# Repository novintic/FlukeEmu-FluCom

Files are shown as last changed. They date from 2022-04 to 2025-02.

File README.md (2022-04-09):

# FlukeEmu-FluCom
A HW/SW solution for Fluke 9010 mainframe emulation

The Idea is to use a Raspberry Pi to run a Fluke 9010a emulator in software and interface with the hardware (pods) by means
of an add on board/hat (basically to shift the levels and provide power to the pod). So far we have progressed from a proof
of concept to a pretty solid and stable emulation.

The advantages of using an approach like this are many, amongst them:
* cheap Fluke 9010a mainframe replacement using modern technology and thereby adding stuff like network capability, wireless LAN, remote access/VNC, bluetooth etc ‚for free‘
* the interface board can supply all the power rails to the pod so only one 12V wall adapter is needed to power the RaspberryPi and the pods
* the whole setup is portable and compact, you could in theory put the whole thing inside your cabinet/UUT and comfortably use VNC to remote control the Fluke. You could also run the thing ‚headless‘ making it even smaller.

For further instruction on the fluCom board, please check: FlukeEmu-FluCom/fluCom/readme.md

For further instruction on the flukeEmuWx software, please check: FlukeEmu-FluCom/flukeEmuWx/readme.md

## Credits
We would like to credit Adam Courchesne (@onecircuit) for coming up with the idea of a Fluke emulator and hardware combination
and of course for being the first one to actually write one and make it available.

## See also
https://forums.arcade-museum.com/threads/flukeemu-flucom-fluke-9010a-microsystem-troubleshooter-emulator.503305/

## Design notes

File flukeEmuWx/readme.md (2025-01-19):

## Instructions for setting up FlukeEmuWx by Clemens (Novintic)

## Easy method:

1) Get a Raspberry PI 2, 3 or 4 with Raspi OS installed
2) Download the install script: https://raw.githubusercontent.com/novintic/FlukeEmu-FluCom/refs/heads/main/flukeEmuWx/build-flukeEmuWx.sh
3) make it executable: chmod u+x build-flukeEmuWx.sh
4) execute the script and wait.
5) Start flukeEmuWx from the menu/others folder

## Advanced method
You need:
* A Raspberry PI 2, 3 or 4 with Raspi OS installed
* Codeblocks IDE (if not installed, use add/remove software)
* Fluke 9010A ROMs 
* To connect a POD you need a FluCom HAT board. KiCad files are in folder: kicad

### Get FlukeEmuWx source files
* Download sources from: https://github.com/novintic/FlukeEmu-FluCom
* Create path: FlukeEmuWx
* Copy source files to path FlukeEmuWx

### Install wxWidgets (Grab a few beers, takes 1-2h!)
* Follow instructions: https://wiki.wxwidgets.org/Compiling_and_getting_started

### Install wiringPi (http://wiringpi.com/news/)
* wget https://unicorn.drogon.net/wiringpi-2.46-1.deb
* sudo dpkg -i wiringpi-2.46-1.deb

### Install pulseAudio
* sudo apt-get install -y libpulse-dev

### Install Fluke ROMs (we cannot supply these due to copyright)
* Copy the 3 ROM files to FlukeEmuWx/media
   * Files have to be named: 128C900.U9, 128C901.U19, 128C902.U21

### Start Codeblocks IDE
* Open project file: FlukeEmuWx/FlukeEmuWx.cbp
* Build the project

### Run flukeEmuWx
* Press the run button in codeblocks
* In order to run flukeEmuWx standalone, you need to place the 'media' folder in the same folder as the executable
   * The executable file 'FlukeEmuWx' is in the bin/Release or bin/Debug folder, depending on which target was built

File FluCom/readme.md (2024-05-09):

# FluCom
The FluCom Interface is a stack-on board (HAT) for a Raspberry Pi 3 or higher. It’s purpose is to interface with Pods for the Fluke 9000 series Microsystem Troubleshooter which is still used today to diagnose and repair vintage computer equipment such as arcade game pcbs.

It is designed to be used in conjunction with the FlukeEmu software.

The idea behind the project is to use readily available parts to provide an as-simple-as-possible (cheap) way to replace a Fluke 9010a Mainframe.

The board and its design files are made available under the CERN Open Hardware License: https://ohwr.org/project/cernohl/wikis/Documents/CERN-OHL-version-2

Novitntic 03/2022

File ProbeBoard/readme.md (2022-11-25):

# Probe add-on- board for FluCom Raspberry Pi HAT

This add-on board for the FluCom Raspberry Pi HAT provides full probe functionality for the FlukeEmu/FluCom hardware/software Emulation of the Fluke 9010A Micro-System Troubleshooter.

Basically this makes the Fluke 9010A emulation feature- complete.

As much of the original circuitry as possible was implemented using a Raspberry PICO microcontroller. 

However, due to the original design of the probe, a significant amount of analog circuitry had to be reproduced in order to keep the system working with legacy probes.

The board and its design files are made available under the CERN Open Hardware License: https://ohwr.org/project/cernohl/wikis/Documents/CERN-OHL-version-2

Novitntic 11/2022

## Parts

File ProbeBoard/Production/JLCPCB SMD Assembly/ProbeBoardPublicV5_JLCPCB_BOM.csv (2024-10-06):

Comment | Designator | Footprint | LCSC
6.8uF 35V | C1,C2 | Capacitor_SMD:C_0805_2012Metric_Pad1.18x1.45mm_HandSolder | C5139488
100uF | C3 | Capacitor_THT:CP_Radial_D5.0mm_P2.50mm
0.1uF | C4,C5 | Capacitor_SMD:C_0805_2012Metric_Pad1.18x1.45mm_HandSolder | C126469
2-10pF | C51 | Capacitor_SMD:C_1210_3225Metric
5-50pF | C52 | Capacitor_SMD:C_1210_3225Metric
0.22uF | C53,C58,C59,C60,C61,C62,C71 | Capacitor_SMD:C_0805_2012Metric_Pad1.18x1.45mm_HandSolder | C152875
.001uF | C54,C55 | Capacitor_SMD:C_0805_2012Metric_Pad1.18x1.45mm_HandSolder | C46553
22uF 15V Tant | C56 | Capacitor_SMD:C_0805_2012Metric_Pad1.18x1.45mm_HandSolder | C77071
10nF | C7 | Capacitor_SMD:C_0805_2012Metric_Pad1.18x1.45mm_HandSolder | C303893
1N4448 | CR3,CR4,CR5,CR6,CR7,CR13 | Diode_SMD:D_SOD-123 | C8601
MBR120(520?) | D1 | Diode_SMD:Nexperia_CFP3_SOD-123W | C130880
LED RED | D2 | LED_SMD:LED_0805_2012Metric_Pad1.15x1.40mm_HandSolder | C94741
LED GREEN | D3 | LED_SMD:LED_0805_2012Metric_Pad1.15x1.40mm_HandSolder | C2297
BSS138 | Q1,Q2,Q4,Q5 | Package_TO_SOT_SMD:SOT-23 | C5190146
10K | R13,R14,R15,R16 | Resistor_SMD:R_0805_2012Metric_Pad1.20x1.40mm_HandSolder | C510098
200R | R22,R23,R41 | Resistor_SMD:R_0805_2012Metric_Pad1.20x1.40mm_HandSolder | C328389
330R | R24 | Resistor_SMD:R_0805_2012Metric_Pad1.20x1.40mm_HandSolder | C328393
150R | R25 | Resistor_SMD:R_0805_2012Metric_Pad1.20x1.40mm_HandSolder | C328383
15K(1%) | R26 | Resistor_SMD:R_0805_2012Metric_Pad1.20x1.40mm_HandSolder | C706307
4420R(1%) | R27 | Resistor_SMD:R_0805_2012Metric_Pad1.20x1.40mm_HandSolder | C185701
200R(1%) | R28 | Resistor_SMD:R_0805_2012Metric_Pad1.20x1.40mm_HandSolder | C328389
100R(1%) | R29 | Resistor_SMD:R_0805_2012Metric_Pad1.20x1.40mm_HandSolder | C706199
300R | R3,R4 | Resistor_SMD:R_0805_2012Metric_Pad1.20x1.40mm_HandSolder | C114529
2.2K | R30,R31 | Resistor_SMD:R_0805_2012Metric_Pad1.20x1.40mm_HandSolder | C163972
22K | R32 | Resistor_SMD:R_0805_2012Metric_Pad1.20x1.40mm_HandSolder
10K? 5K? | R33 | Resistor_SMD:R_0805_2012Metric_Pad1.20x1.40mm_HandSolder
750R | R38 | Resistor_SMD:R_0805_2012Metric_Pad1.20x1.40mm_HandSolder | C416169
1K | R5,R6,R10,R11,R39 | Resistor_SMD:R_0805_2012Metric_Pad1.20x1.40mm_HandSolder | C115316
100R | R52 | Resistor_SMD:R_0805_2012Metric_Pad1.20x1.40mm_HandSolder | C706199
510R | R56 | Resistor_SMD:R_0805_2012Metric_Pad1.20x1.40mm_HandSolder | C228886
JFE2140 | U1 | Package_SO:SOIC-8_3.9x4.9mm_P1.27mm | C2915160
LM361 | U2,U3 | Package_SO:SOIC-14_3.9x8.7mm_P1.27mm | C2868536
SN74LV1T34DBV | U4,U6 | Package_TO_SOT_SMD:SOT-23-5 | C100024

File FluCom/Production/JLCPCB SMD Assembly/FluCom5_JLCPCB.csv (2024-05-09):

Comment | Designator | Footprint | LCSC
0.1uF | C1,C2,C3,C4,C5,C6,C9,C10 | Capacitor_SMD:C_0805_2012Metric_Pad1.18x1.45mm_HandSolder | C138340
4.7uF | C7 | Capacitor_SMD:C_0805_2012Metric_Pad1.18x1.45mm_HandSolder | C77077
10uF | C8 | Capacitor_SMD:C_0805_2012Metric_Pad1.18x1.45mm_HandSolder | C83061
B320 | D1 | Diode_SMD:D_SMC | C134448
LED_Small | D2,D3,D4,D5 | LED_SMD:LED_0805_2012Metric_Pad1.15x1.40mm_HandSolder | C189307
BSS138 | Q1,Q2 | Package_TO_SOT_SMD:SOT-23 | C5190146
R_Small | R1 | Resistor_SMD:R_0805_2012Metric_Pad1.20x1.40mm_HandSolder | C510098
300R | R10,R11,R13 | Resistor_SMD:R_0805_2012Metric_Pad1.20x1.40mm_HandSolder | C365284
700R | R12 | Resistor_SMD:R_0805_2012Metric_Pad1.20x1.40mm_HandSolder | C229239
10K | R2,R3,R4,R5,R14 | Resistor_SMD:R_0805_2012Metric_Pad1.20x1.40mm_HandSolder | C510098
TXS0104EPW | U1,U2,U3 | Package_SO:SOIC-14_3.9x8.7mm_P1.27mm | C79342
SN74LV1T34DBV | U6,U7 | Package_TO_SOT_SMD:SOT-23-5 | C100024

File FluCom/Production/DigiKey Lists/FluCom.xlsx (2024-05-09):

Das Herkunftsland kann sich zum Zeitpunkt des Versands geändert haben.
Die angezeigten HTSUS- und ECCN-Informationen dienen nur zu Informationszwecken und stellen keine Zusicherung oder Garantie für die Richtigkeit oder Zuverlässigkeit dieser Klassifizierungen dar. Alle Informationen werden ohne Gewähr zur Verfügung gestellt und können ohne vorherige Ankündigung geändert werden. Jede Verwendung der bereitgestellten Informationen erfolgt ohne Rechtsansprüche an Digi-Key und auf Risiko des Benutzers.
Index | Hersteller-Teilenummer | Herstellername | Beschreibung | Verfügbarkeit | Lagerstatus | Verlust % | Gewünschte Menge 1 | Packungsmenge 1 | Packungstyp 1 | Digi-Key-Teilenr. 1 | Stückpreis 1 | Gesamtpreis 1 | Mindestbestellmenge 1 | Kundenreferenz | Gewünschte Teilenummer | Lieferzeit in Wochen | Datenblatt | Referenzbezeichner | US-Einfuhrzoll | Hinweis | Status der Komponente | RoHS-Status | Feuchteempfindlichkeit (MSL) | ECCN | HTSUS | Herkunftsland | Informationen zur Umweltverträglichkeit | Original-Teilenummern | Bild | Product Notes
1 | 5747842-3 | TE Connectivity AMP Connectors | CONN D-SUB PLUG 25POS R/A SLDR | 513 | Artikel auf Lager |  | 1 | 1 | Tray | A32099-ND | 4.91000 | Fr. 4.91 | 1 |  | A32099-ND | 11 | https://www.te.com/commerce/DocumentDelivery/DDEController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 |  | N/A |  | Aktiv | RoHS-konform | 1 (Unbegrenzt) | EAR99 | 8536.69.4040 | Mexico | http://www.te.com/commerce/alt/SinglePartSearch.do?PN=5747842-3&dest=stmt | A32099-ND | https://mm.digikey.com/Volume0/opasdata/d220001/medias/images/922/5747842-3.jpg
2 | TB004-508-02BE | CUI Devices | TERMINAL BLOCK, SCREW TYPE, 5.08 | 425 | Artikel auf Lager |  | 2 | 2 | Bag | 102-6179-ND | 0.53000 | Fr. 1.06 | 1 |  | 102-6179-ND | 18 | https://www.cuidevices.com/product/resource/tb004-508.pdf |  | Gilt unter Umständen für Lieferungen in die USA. |  | Aktiv | RoHS3-konform | Nicht anwendbar | EAR99 | 8536.90.4000 | China | https://www.cuidevices.com/product/resource/ce-declaration/tb004-508-series|https://www.cuidevices.com/product/resource/material-compliance/tb004-508-series | 102-6179-ND | https://mm.digikey.com/Volume0/opasdata/d220001/medias/images/568/MFG_TB004-508-02BE.jpg
3 | TB004-508-03BE | CUI Devices | TERMINAL BLOCK, SCREW TYPE, 5.08 | 994 | Artikel auf Lager |  | 1 | 1 | Bag | 102-6180-ND | 0.79000 | Fr. 0.79 | 1 |  | 102-6180-ND | 18 | https://www.cuidevices.com/product/resource/tb004-508.pdf |  | Gilt unter Umständen für Lieferungen in die USA. |  | Aktiv | RoHS3-konform | Nicht anwendbar | EAR99 | 8536.90.4000 | China | https://www.cuidevices.com/product/resource/ce-declaration/tb004-508-series|https://www.cuidevices.com/product/resource/material-compliance/tb004-508-series | 102-6180-ND | https://mm.digikey.com/Volume0/opasdata/d220001/medias/images/568/MFG_TB004-508-03BE.jpg
4 | B0505S-1WR3 | Mornsun America, LLC | DC DC CONVERTER 5V 1W | 26’061 | Artikel auf Lager |  | 1 | 1 | Tube | 2725-B0505S-1WR3-ND | 4.55000 | Fr. 4.55 | 1 |  | 2725-B0505S-1WR3-ND | 15 | https://www.mornsun-power.com/html/pdf/B0505S-1WR3.html |  | Gilt unter Umständen für Lieferungen in die USA. |  | Aktiv | RoHS-konform | 1 (Unbegrenzt) | EAR99 | 8504.40.9580 | China |  | 2725-B0505S-1WR3-ND | https://mm.digikey.com/Volume0/opasdata/d220001/medias/images/4414/MFG_B0505S-1WR3.JPG
5 | PJ-059AH | CUI Devices | CONN PWR JACK 2X5.5MM SOLDER | 1’160 | Artikel auf Lager |  | 1 | 1 | Tray | CP-059AH-ND | 0.84000 | Fr. 0.84 | 1 |  | CP-059AH-ND | 7 | https://www.cuidevices.com/product/resource/pj-059ah.pdf |  | N/A |  | Aktiv | RoHS3-konform | 1 (Unbegrenzt) | EAR99 | 8536.69.4040 | China | https://www.cuidevices.com/product/resource/material-compliance/pj-059ah | CP-059AH-ND | https://mm.digikey.com/Volume0/opasdata/d220001/medias/images/923/PJ-059AH.JPG
6 | PPPC202LFBN-RC | Sullins Connector Solutions | CONN HDR 40POS 0.1 GOLD PCB | 93’538 | Artikel auf Lager |  | 1 | 1 | Tray | S7123-ND | 2.09000 | Fr. 2.09 | 1 |  | S7123-ND | 11 | https://mm.digikey.com/Volume0/opasdata/d220001/medias/docus/937/Female_Headers.100_DS.pdf |  | N/A |  | Aktiv | RoHS3-konform | 1 (Unbegrenzt) | EAR99 | 8536.69.4040 | Taiwan | https://www.sullinscorp.com/wp-content/uploads/2021/08/Sullins-REACH-219-SVHC-Compliant-Statement.pdf|https://www.sullinscorp.com/wp-content/uploads/2019/03/Sullins-RoHS-Compliant-Statement.pdf | S7123-ND | https://mm.digikey.com/Volume0/opasdata/d220001/medias/images/1144/PPPC202LFBN-RC.jpg
7 | 67997-226HLF | Amphenol ICC (FCI) | CONN HEADER VERT 26POS 2.54MM | 3’237 | Artikel auf Lager |  | 1 | 1 | Bag | 609-3240-ND | 1.30000 | Fr. 1.30 | 1 |  | 609-3240-ND | 22 | https://cdn.amphenol-cs.com/media/wysiwyg/files/drawing/67996.pdf |  | N/A |  | Aktiv | RoHS-konform | 1 (Unbegrenzt) | EAR99 | 8536.69.4040 | France |  | 609-3240-ND | https://mm.digikey.com/Volume0/opasdata/d220001/medias/images/2511/67997-xxx.jpg
8 | SSW-120-02-G-D-LL | Samtec Inc. | CONN RCPT 40POS 0.1 GOLD PCB | 333 | Artikel auf Lager |  | 1 | 1 | Bulk | SSW-120-02-G-D-LL-ND | 7.92000 | Fr. 7.92 | 1 |  | SSW-120-02-G-D-LL-ND | 5 | https://suddendocs.samtec.com/productspecs/tsw-sxx.pdf |  | N/A |  | Aktiv | RoHS3-konform | Nicht anwendbar | EAR99 | 8536.69.4040 | Malaysia |  | SSW-120-02-G-D-LL-ND | https://mm.digikey.com/Volume0/opasdata/d220001/medias/images/4842/SSW-120-02-G-D-LL.jpg
9 | SSW-120-01-G-D-LL | Samtec Inc. | CONN RCPT 40POS 0.1 GOLD PCB | 22 | Artikel auf Lager |  | 1 | 1 | Bulk | SSW-120-01-G-D-LL-ND | 7.68000 | Fr. 7.68 | 1 |  | SSW-120-01-G-D-LL-ND | 5 | https://suddendocs.samtec.com/productspecs/tsw-sxx.pdf |  | N/A |  | Aktiv | RoHS3-konform | Nicht anwendbar | EAR99 | 8536.69.4040 | Vietnam |  | SSW-120-01-G-D-LL-ND | https://mm.digikey.com/Volume0/opasdata/d220001/medias/images/4840/SSW-120-01-G-D-LL.jpg
10 | SMH150-LPSE-D25-ST-BK | Sullins Connector Solutions | CONN HEADER VERT 50POS 1MM | 1’234 | Artikel auf Lager |  | 1 | 1 | Bag | S9258-ND | 8.11000 | Fr. 8.11 | 1 |  | S9258-ND | 11 | https://s3.amazonaws.com/catalogspreads-pdf/PAGE88-89%201mm%20SMH%20SERIES%20MALE%20HDR%20ST%20RA%20SMT.pdf |  | N/A |  | Aktiv | RoHS3-konform | 1 (Unbegrenzt) | EAR99 | 8536.69.4040 | Taiwan | https://www.sullinscorp.com/wp-content/uploads/2021/08/Sullins-REACH-219-SVHC-Compliant-Statement.pdf|https://www.sullinscorp.com/wp-content/uploads/2019/03/Sullins-RoHS-Compliant-Statement.pdf | S9258-ND | https://mm.digikey.com/Volume0/opasdata/d220001/medias/images/606/SMH150-LPSE-D25-ST-BK.JPG
11 | QPC02SXGN-RC | Sullins Connector Solutions | CONN JUMPER SHORTING .100" GOLD | 60’764 | Artikel auf Lager |  | 8 | 8 | Bag | S9337-ND | 0.09000 | Fr. 0.72 | 1 |  | S9337-ND | 11 | https://s3.amazonaws.com/catalogspreads-pdf/PAGE128-129%20.100%20JUMPER.pdf |  | N/A |  | Aktiv | RoHS3-konform | 1 (Unbegrenzt) | EAR99 | 8536.90.4000 | Taiwan | https://www.sullinscorp.com/wp-content/uploads/2021/08/Sullins-REACH-219-SVHC-Compliant-Statement.pdf|https://www.sullinscorp.com/wp-content/uploads/2019/03/Sullins-RoHS-Compliant-Statement.pdf | S9337-ND | https://mm.digikey.com/Volume0/opasdata/d220001/medias/images/386/QPC02SXGN-RC.JPG

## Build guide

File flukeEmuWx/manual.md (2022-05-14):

# FlukeEmuWx User Manual

## 1 Introduction
FlukeEmuWx is a software which emulates a Fluke 9010A mainframe on a Raspberry Pie (RPI) computer. FlukeEmuWx use the GPIOs on the RPI to communicate with the pods. Since the RPI outputs are 3.3V and the pod are running on 5V, a level converter board is required (the FluCom2).
FlukeEmuWx works by running a Z80 emulator that executes the original ROM code. The user interface elements like display and keyboard are emulated on the RPI.

## 2 Installation
See readme.txt for how to build FlukeEmuWx or check out the nice manuals on [1] by cyberbarter.

The media folder either needs to be in the same folder as the executable or you have to add the path of the media folder the environment variable PATH.

[1] https://forums.arcade-museum.com/threads/flukeemu-flucom-fluke-9010a-microsystem-troubleshooter-emulator.503305/page-5 

## 3 Features
### 3.1 Tape drive emulation
Clicking the tape icon in the top right corner opens a file dialog where you can select a tape file. Alternatively you can use the settings menu entry 'Tape file'. The tape file must exist already  (use touch yourfile.txt on the command line to create an empty file for writing).

### 3.2 Serial port emulation
#### 3.2.1 Host serial port
Setting the serial port flukeEmuWx will route the Fluke 9010B serial port to a real serial port on your RPI. 
The serial port on the RPI GPIOs is named /dev/serial0. You will need a converter board (like FTDI TTL232R, 3.3v levels) to connect the RPI UART to a USB port on a PC. The permissions for the current user to access the serial port file must be set correctly. This is done by adding the current user to the group 'tty'. The port might be already in use by a serial console. In this case you need to disable the console using "sudo raspi-config" (interface options, disable console, enable serial port hardware).

#### 3.2.1 Serial port to/from file
In order to send a file to the serial port of the Fluke 9010 emulation, select 'send file' in the settings/serial port menu. This will
open a file dialog, where you can choose the file. Once done, the file content will be fed to the Fluke 9010 serial port as soon as
you read from the port. If the file has been fully read, it will be automatically closed.

In order to receive a file from the emulation, select 'receive file' in the settings/serial port menu. This will
open a file dialog, where you can choose the file. Once done, any data sent through the serial port of the Fluke 9010 emulation 
will be written to this file. To detach the file from the serial port, select 'receive file' in the menu and press cancel in the file dialog.

### 3.3 Full screen mode
Enter fullscreen by 
* using the menu "settings/fullscreen"
* Pressing F5
* Left click in the (Fluke emulation) display area and use the pop-up menu
Exit fullscreen by 
* Pressing F5
* Left click in the (Fluke emulation) display area and use the pop-up menu

## Appendix
### A.1 Using FlukeEmuWx over VNC
A convienent way of using FlukeEmuWx on the RPI is to use VNC. This allows you to use the screen, keyboard and mouse
of the computer running the VNC client. You do not need a screen or keyobard connected to the RPI, but the RPI needs
a network connection, either by Ethernet or WLAN. Realvnc is a good choice for a VNC client for For windows.

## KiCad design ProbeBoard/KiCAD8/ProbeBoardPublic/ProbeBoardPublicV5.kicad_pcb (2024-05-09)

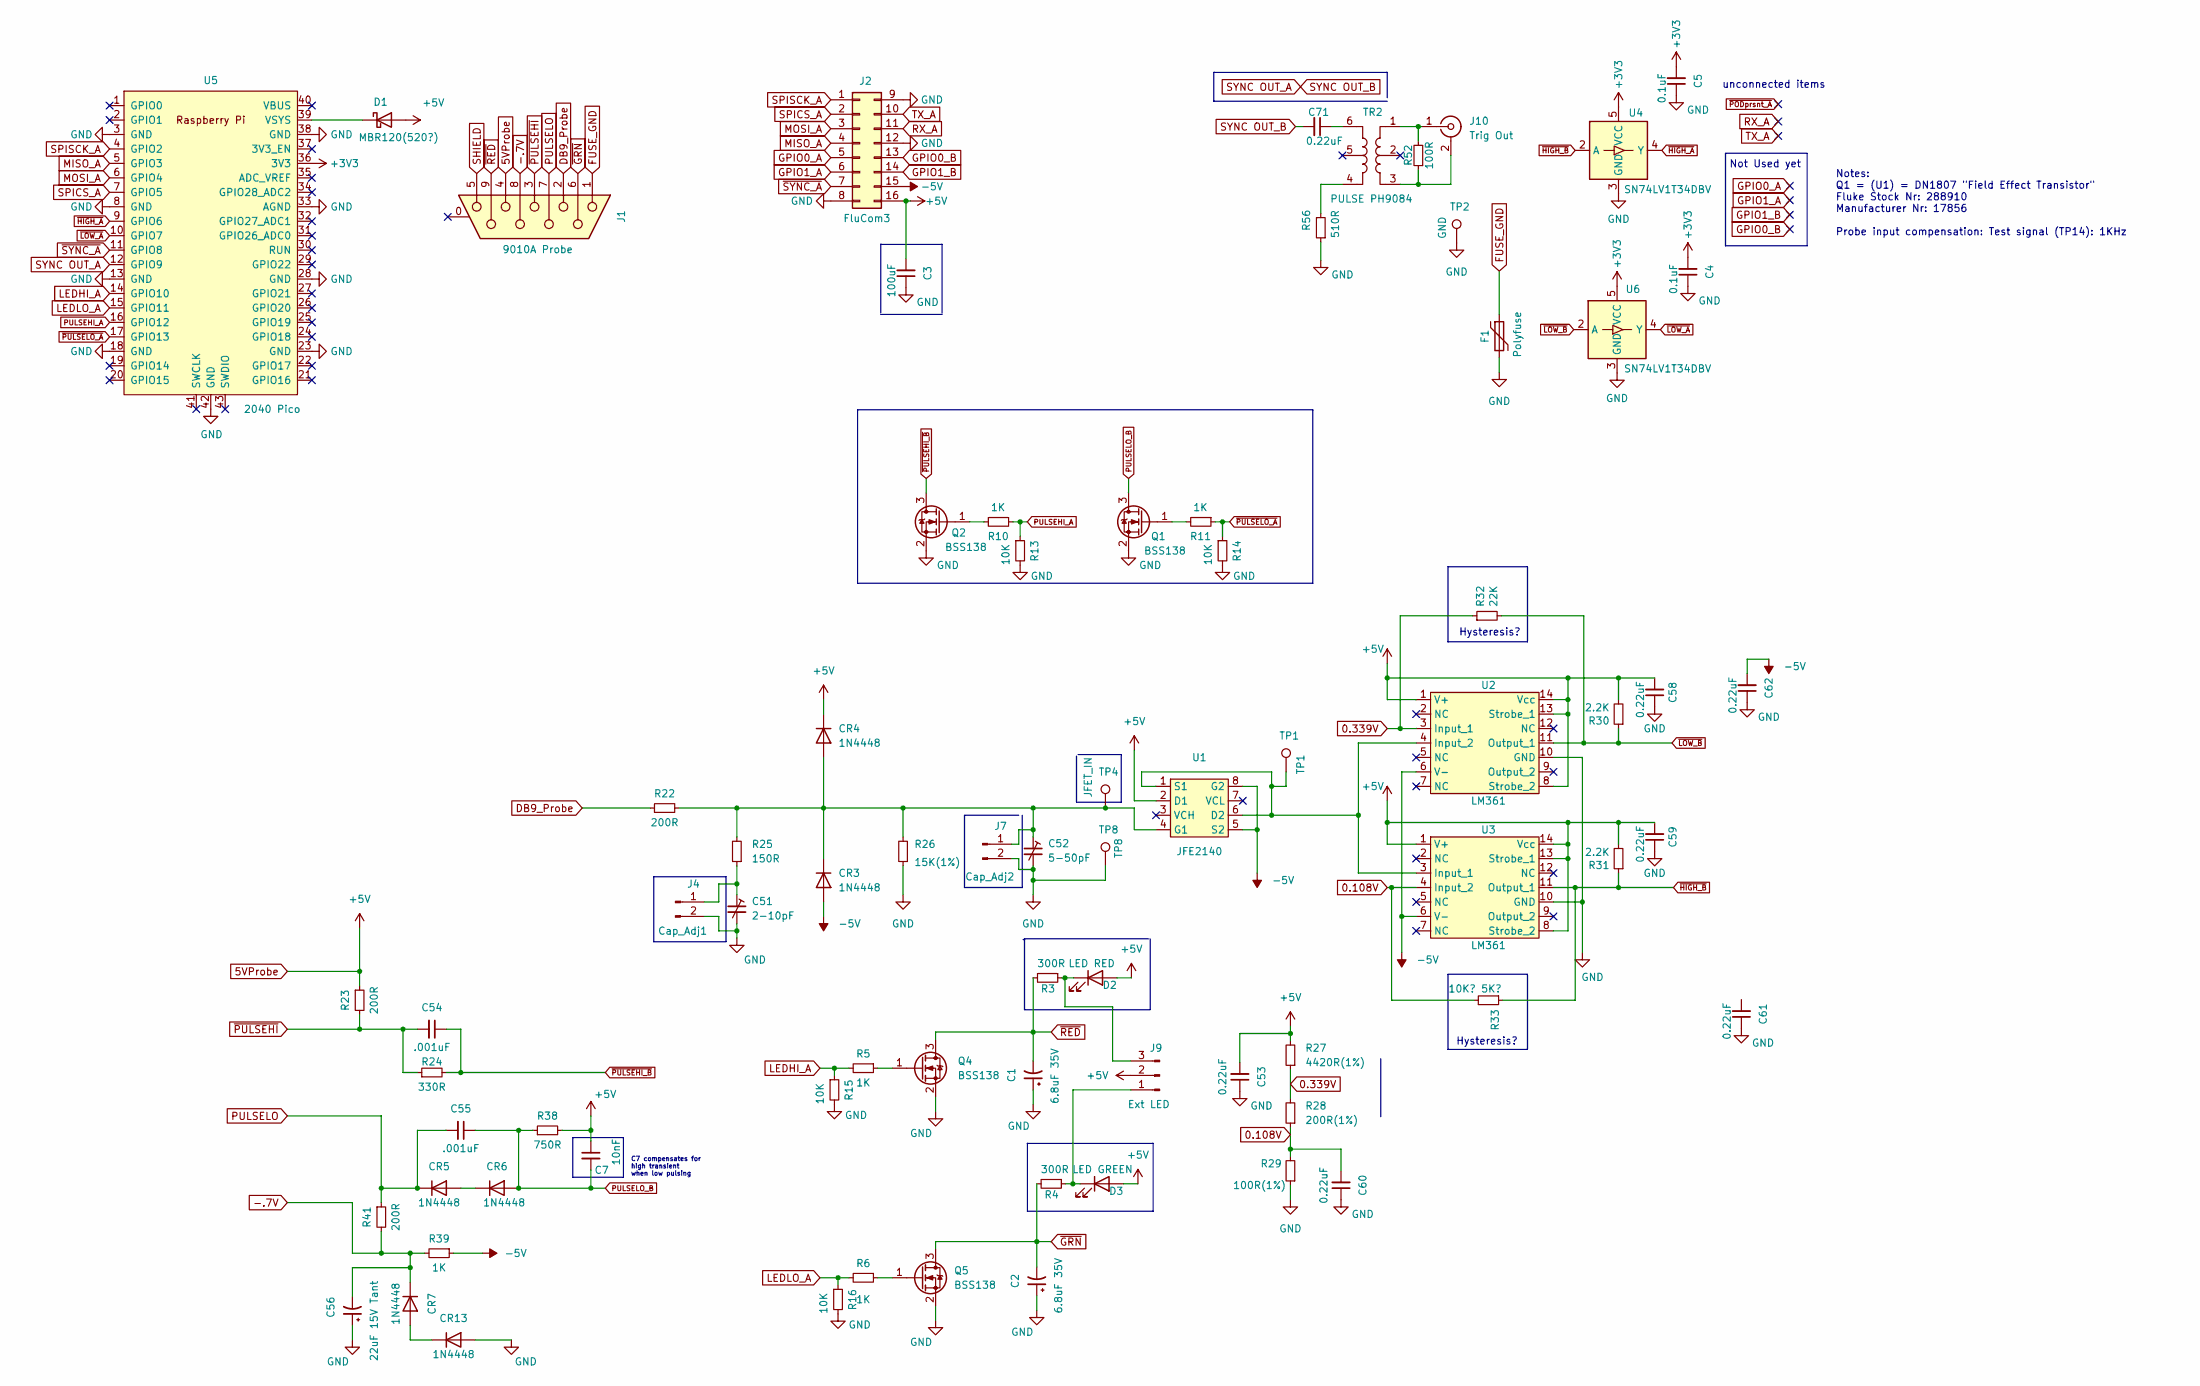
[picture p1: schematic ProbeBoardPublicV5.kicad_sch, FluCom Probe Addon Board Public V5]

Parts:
C1, C2: 6.8uF 35V; C_0805_2012Metric_Pad1.18x1.45mm_HandSolder; LCSC C5139488
C3: 100uF; CP_Radial_D5.0mm_P2.50mm
C4, C5: 0.1uF; C_0805_2012Metric_Pad1.18x1.45mm_HandSolder; LCSC C126469
C7: 10nF; C_0805_2012Metric_Pad1.18x1.45mm_HandSolder; LCSC C303893
C51: 2-10pF; C_1210_3225Metric
C52: 5-50pF; C_1210_3225Metric
C53, C58, C59, C60, C61, C62, C71: 0.22uF; C_0805_2012Metric_Pad1.18x1.45mm_HandSolder; LCSC C152875
C54, C55: .001uF; C_0805_2012Metric_Pad1.18x1.45mm_HandSolder; LCSC C46553
C56: 22uF 15V Tant; C_0805_2012Metric_Pad1.18x1.45mm_HandSolder; LCSC C77071
CR3, CR4, CR5, CR6, CR7, CR13: 1N4448; D_SOD-123; LCSC C8601
D1: MBR120(520?); Nexperia_CFP3_SOD-123W; LCSC C130880
D2: LED RED; LED_0805_2012Metric_Pad1.15x1.40mm_HandSolder; LCSC C94741
D3: LED GREEN; LED_0805_2012Metric_Pad1.15x1.40mm_HandSolder; LCSC C2297
F1: Polyfuse; C_1206_3216Metric_Pad1.33x1.80mm_HandSolder
J1: 9010A Probe; DSUB-9_Female_Horizontal_P2.77x2.84mm_EdgePinOffset4.94mm_H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
J2: FluCom3; PinHeader_2x08_P2.54mm_Vertical
J4: Cap_Adj1; PinHeader_1x02_P2.54mm_Vertical
J7: Cap_Adj2; PinHeader_1x02_P2.54mm_Vertical
J9: Ext LED; PinHeader_1x03_P2.54mm_Vertical
J10: Trig Out; BNC_Amphenol_B6252HB-NPP3G-50_Horizontal
Q1, Q2, Q4, Q5: BSS138; SOT-23; LCSC C5190146
R3, R4: 300R; R_0805_2012Metric_Pad1.20x1.40mm_HandSolder; LCSC C114529
R5, R6, R10, R11, R39: 1K; R_0805_2012Metric_Pad1.20x1.40mm_HandSolder; LCSC C115316
R13, R14, R15, R16: 10K; R_0805_2012Metric_Pad1.20x1.40mm_HandSolder; LCSC C510098
R22, R23, R41: 200R; R_0805_2012Metric_Pad1.20x1.40mm_HandSolder; LCSC C328389
R24: 330R; R_0805_2012Metric_Pad1.20x1.40mm_HandSolder; LCSC C328393
R25: 150R; R_0805_2012Metric_Pad1.20x1.40mm_HandSolder; LCSC C328383
R26: 15K(1%); R_0805_2012Metric_Pad1.20x1.40mm_HandSolder; LCSC C706307
R27: 4420R(1%); R_0805_2012Metric_Pad1.20x1.40mm_HandSolder; LCSC C185701
R28: 200R(1%); R_0805_2012Metric_Pad1.20x1.40mm_HandSolder; LCSC C328389
R29: 100R(1%); R_0805_2012Metric_Pad1.20x1.40mm_HandSolder; LCSC C706199
R30, R31: 2.2K; R_0805_2012Metric_Pad1.20x1.40mm_HandSolder; LCSC C163972
R32: 22K; R_0805_2012Metric_Pad1.20x1.40mm_HandSolder
R33: 10K? 5K?; R_0805_2012Metric_Pad1.20x1.40mm_HandSolder
R38: 750R; R_0805_2012Metric_Pad1.20x1.40mm_HandSolder; LCSC C416169
R52: 100R; R_0805_2012Metric_Pad1.20x1.40mm_HandSolder; LCSC C706199
R56: 510R; R_0805_2012Metric_Pad1.20x1.40mm_HandSolder; LCSC C228886
TP1: TP1; PinHeader_1x01_P2.54mm_Vertical
TP2: GND; PinHeader_1x01_P2.54mm_Vertical
TP4: JFET_IN; PinHeader_1x01_P2.54mm_Vertical
TP8: TP8; PinHeader_1x01_P2.54mm_Vertical
TR2: PULSE PH9084; Pulse_P0926NL
U1: JFE2140; SOIC-8_3.9x4.9mm_P1.27mm; LCSC C2915160
U2, U3: LM361; SOIC-14_3.9x8.7mm_P1.27mm; LCSC C2868536
U4, U6: SN74LV1T34DBV; SOT-23-5; LCSC C100024
U5: 2040 Pico; RPi_Pico_SMD_TH

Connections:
0.108V: C60.2, R28.1, R29.2, R33.2, U3.4 (Input_2)
0.339V: R27.1, R28.2, R32.1, U2.3 (Input_1)
5VProbe: C3.2, C7.1, C53.2, C58.2, C59.2, CR4.1 (K), D1.2 (A), D2.2 (A), D3.2 (A), J1.4, J2.16, J9.2, R23.1, R27.2, R30.2, R31.2, R38.2, U1.2 (D1), U2.1 (V+), U2.8 (Strobe_2), U2.13 (Strobe_1), U2.14 (Vcc), U3.1 (V+), U3.8 (Strobe_2), U3.13 (Strobe_1), U3.14 (Vcc)
+3V3: C4.2, C5.2, U4.5 (VCC), U5.36 (3V3), U6.5 (VCC)
-5V: C62.2, CR3.2 (A), J2.15, R39.1, U1.5 (S2), U1.8 (G2), U2.6 (V-), U3.6 (V-)
-.7V: C56.2, CR7.1 (K), J1.8, R39.2, R41.2
DB9_Probe: J1.2, R22.1
FUSE_GND: F1.1, J1.1
GND: C1.1, C2.1, C3.1, C4.1, C5.1, C51.2, C52.2, C53.1, C56.1, C58.1, C59.1, C60.1, C61.1, C62.1, CR13.2 (A), F1.2, J2.8, J2.9, J2.12, J4.2, J7.2, Q1.2 (S), Q2.2 (S), Q4.2 (S), Q5.2 (S), R13.2, R14.2, R15.2, R16.2, R26.1, R29.1, R56.1, TP2.1, TP8.1, U2.10 (GND), U3.10 (GND), U4.3 (GND), U5.3 (GND), U5.8 (GND), U5.13 (GND), U5.18 (GND), U5.23 (GND), U5.28 (GND), U5.33 (AGND), U5.38 (GND), U5.42 (GND), U6.3 (GND)
GPIO0_A: J2.5
GPIO0_B: J2.13
GPIO1_A: J2.6
GPIO1_B: J2.14
LEDHI_A: R5.2, R15.1, U5.14 (GPIO10)
LEDLO_A: R6.2, R16.1, U5.15 (GPIO11)
MISO_A: J2.4, U5.5 (GPIO3)
MOSI_A: J2.3, U5.6 (GPIO4)
unnamed: C71.1, TR2.6
unnamed: C52.1, CR3.1 (K), CR4.2 (A), J7.1, R22.2, R25.2, R26.2, TP4.1, U1.4 (G1)
unnamed: CR5.2 (A), CR6.1 (K)
unnamed: CR7.2 (A), CR13.1 (K)
unnamed: D1.1 (K), U5.39 (VSYS)
unnamed: D2.1 (K), J9.3, R3.1
unnamed: D3.1 (K), J9.1, R4.1
unnamed: C51.1, J4.1, R25.1
unnamed: J10.2 (Ext), R52.1, TR2.3
unnamed: J10.1 (In), R52.2, TR2.1
unnamed: Q1.1 (G), R11.2
unnamed: Q2.1 (G), R10.2
unnamed: Q4.1 (G), R5.1
unnamed: Q5.1 (G), R6.1
unnamed: R56.2, TR2.4
unnamed: TP1.1, U1.1 (S1), U1.6 (D2), U2.4 (Input_2), U3.3 (Input_1)
PULSEHI_A: R10.1, R13.1, U5.16 (GPIO12)
PULSELO: C55.2, CR5.1 (K), J1.7, R41.1
PULSELO_B: C7.2, C55.1, CR6.2 (A), Q1.3 (D), R38.1
RX_A: J2.11
SHIELD: J1.5
SPICS_A: J2.2, U5.7 (GPIO5)
SPISCK_A: J2.1, U5.4 (GPIO2)
SYNC OUT_A: C71.2, U5.12 (GPIO9)
TX_A: J2.10
~GRN: C2.2, J1.6, Q5.3 (D), R4.2
~HIGH_A: U4.4 (Y), U5.9 (GPIO6)
~HIGH_B: R31.1, R33.1, U3.11 (Output_1), U4.2 (A)
~LOW_A: U5.10 (GPIO7), U6.4 (Y)
~LOW_B: R30.1, R32.2, U2.11 (Output_1), U6.2 (A)
~PULSEHI_B: C54.1, Q2.3 (D), R24.2
~PULSEHI: C54.2, J1.3, R23.2, R24.1
~PULSELO_A: R11.1, R14.1, U5.17 (GPIO13)
~RED: C1.2, J1.9, Q4.3 (D), R3.2
~SYNC_A: J2.7, U5.11 (GPIO8)

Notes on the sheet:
Hysteresis?
C7 compensates for high transient when low pulsing
unconnected items
Notes: Q1 = (U1) = DN1807 "Field Effect Transistor" Fluke Stock Nr: 288910 Manufacturer Nr: 17856 Probe input compensation: Test signal (TP14): 1KHz
Not Used yet

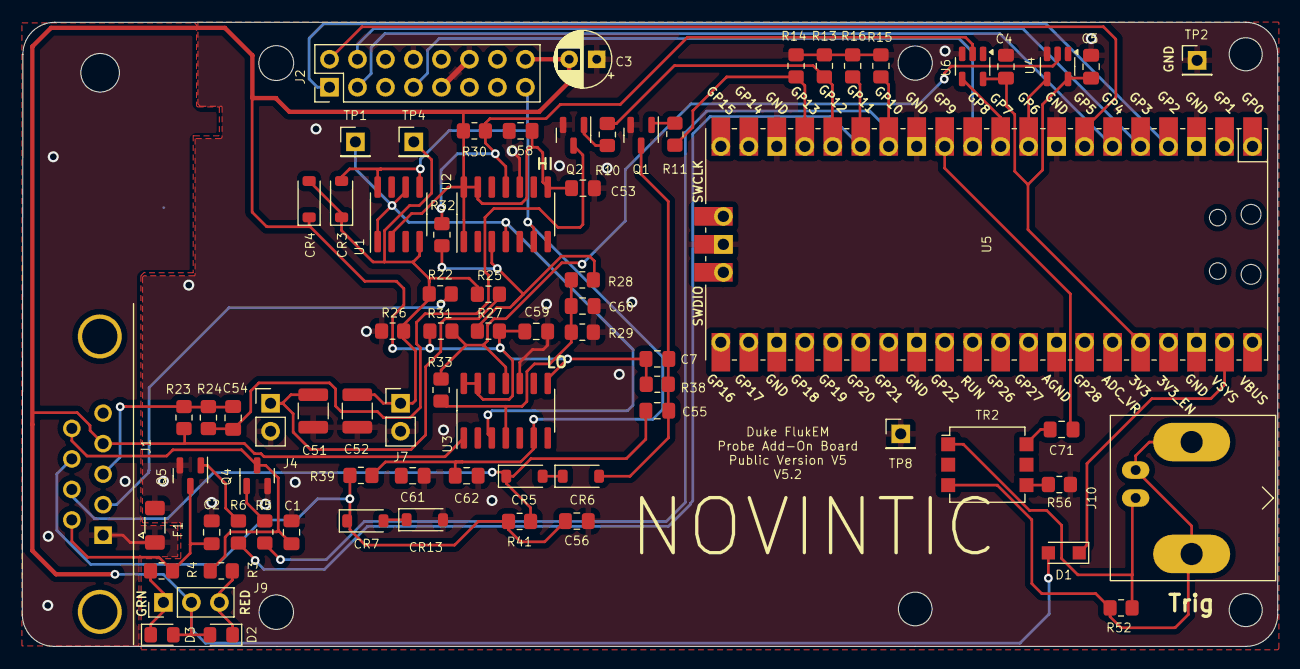
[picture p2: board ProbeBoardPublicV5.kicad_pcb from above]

Board: 2 copper layers, 114.0 x 56.6 mm, 76 parts (0 on the bottom side), 45 nets.

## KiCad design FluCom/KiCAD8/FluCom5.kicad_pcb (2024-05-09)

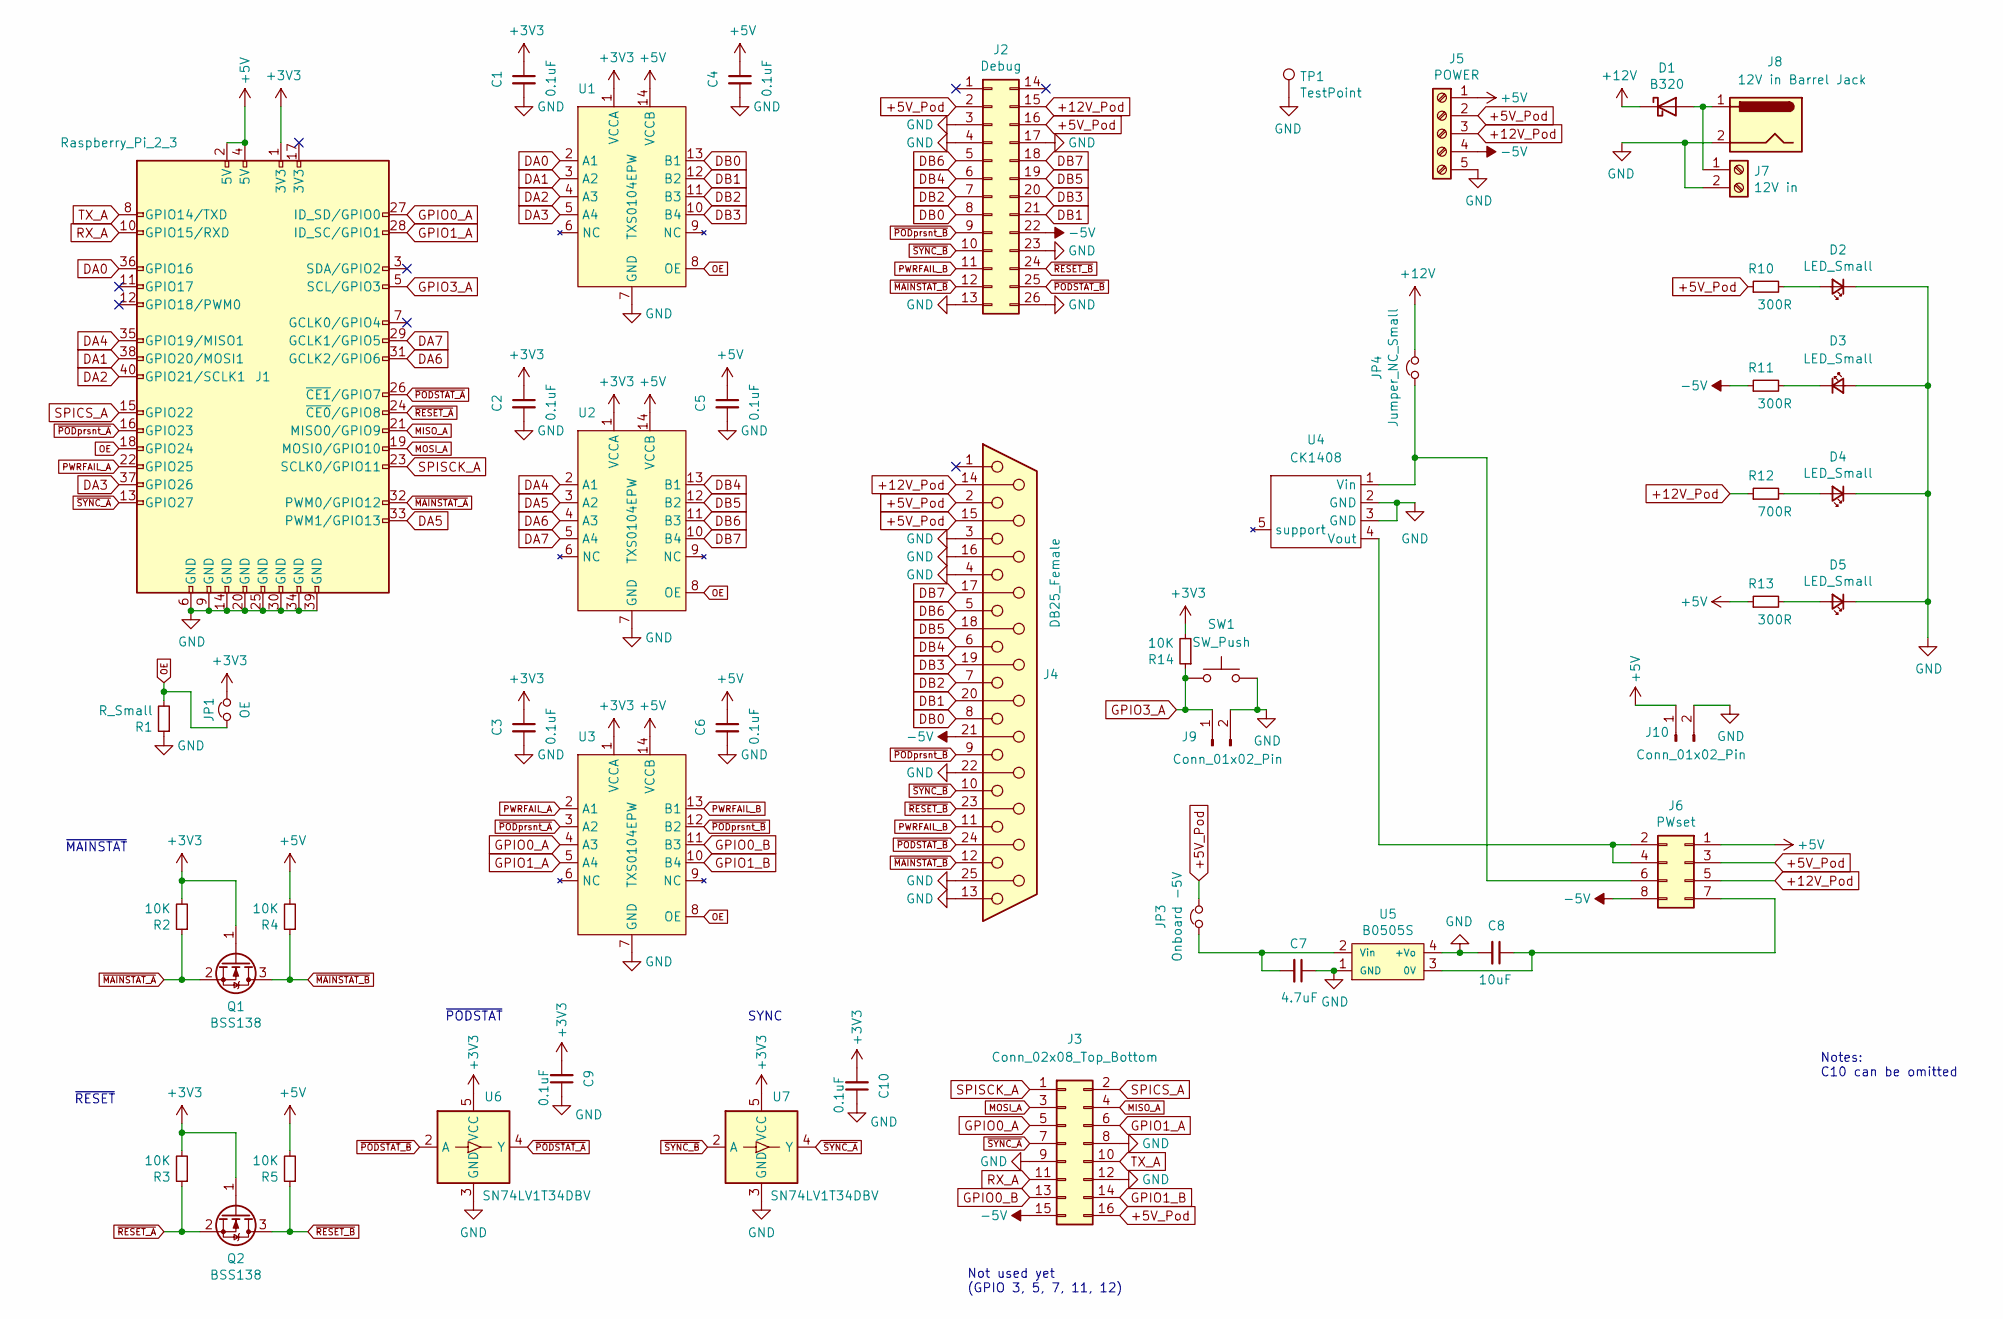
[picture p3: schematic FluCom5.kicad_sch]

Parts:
C1, C2, C3, C4, C5, C6: 0.1uF; C_0805_2012Metric_Pad1.18x1.45mm_HandSolder; LCSC C138340
C7: 4.7uF; C_0805_2012Metric_Pad1.18x1.45mm_HandSolder; LCSC C77077
C8: 10uF; C_0805_2012Metric_Pad1.18x1.45mm_HandSolder; LCSC C83061
C9, C10: 0.1uF; C_0805_2012Metric_Pad1.18x1.45mm_HandSolder; LCSC C126469
D1: B320; D_SMC; LCSC C134448
D2, D3, D4, D5: LED_Small; LED_0805_2012Metric_Pad1.15x1.40mm_HandSolder; LCSC C189307
J1: Raspberry_Pi_2_3; PinHeader_2x20_P2.54mm_Vertical
J2: Debug; PinHeader_2x13_P2.54mm_Vertical_Fluke_Numbering_mirrored
J3: Conn_02x08_Top_Bottom; PinHeader_2x08_P2.54mm_Vertical
J4: DB25_Female; DSUB-25_Female_Horizontal_P2.77x2.54mm_EdgePinOffset9.40mm
J5: POWER; TerminalBlock_bornier-5_P5.08mm
J6: PWset; PinHeader_2x04_P2.54mm_Vertical
J7: 12V in; TerminalBlock_bornier-2_P5.08mm
J8: 12V in Barrel Jack; BarrelJack_Horizontal
J9, J10: Conn_01x02_Pin; PinHeader_1x02_P2.54mm_Vertical
JP1: OE; PinHeader_1x02_P2.54mm_Vertical
JP3: Onboard -5V; PinHeader_1x02_P2.54mm_Vertical
JP4: Jumper_NC_Small; PinHeader_1x02_P2.54mm_Vertical
Q1, Q2: BSS138; SOT-23; LCSC C5190146
R1: R_Small; R_0805_2012Metric_Pad1.20x1.40mm_HandSolder; LCSC C510098
R2, R3, R4, R5, R14: 10K; R_0805_2012Metric_Pad1.20x1.40mm_HandSolder; LCSC C510098
R10, R11, R13: 300R; R_0805_2012Metric_Pad1.20x1.40mm_HandSolder; LCSC C365284
R12: 700R; R_0805_2012Metric_Pad1.20x1.40mm_HandSolder; LCSC C229239
SW1: SW_Push; SW_Push_1P1T_NO_CK_KSC6xxJ
TP1: TestPoint; PinHeader_1x01_P2.54mm_Vertical
U1, U2, U3: TXS0104EPW; SOIC-14_3.9x8.7mm_P1.27mm; LCSC C79342
U4: CK1408
U5: B0505S; Converter_DCDC_muRata_CRE1xxxxxxSC_THT
U6, U7: SN74LV1T34DBV; SOT-23-5; LCSC C100024

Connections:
+3V3: C1.1, C2.1, C3.1, C9.2, C10.2, J1.1 (3V3), JP1.2, Q1.1 (G), Q2.1 (G), R2.2, R3.2, R14.2, U1.1 (VCCA), U2.1 (VCCA), U3.1 (VCCA), U6.5 (VCC), U7.5 (VCC)
+5V: C4.1, C5.1, C6.1, J1.2 (5V), J1.4 (5V), J5.1, J6.1, J10.1, R4.2, R5.2, R13.1, U1.14 (VCCB), U2.14 (VCCB), U3.14 (VCCB)
+5V_Pod: J2.2, J2.16, J3.16, J4.2, J4.15, J5.2, J6.3, JP3.2, R10.1
+12V: D1.1 (K), JP4.2
+12V_Pod: J2.15, J4.14, J5.3, J6.5, R12.1
-5V: J2.22, J3.15, J4.21, J5.4, J6.8, R11.1
DA0: J1.36 (GPIO16), U1.2 (A1)
DA1: J1.38 (GPIO20/MOSI1), U1.3 (A2)
DA2: J1.40 (GPIO21/SCLK1), U1.4 (A3)
DA3: J1.37 (GPIO26), U1.5 (A4)
DA4: J1.35 (GPIO19/MISO1), U2.2 (A1)
DA5: J1.33 (PWM1/GPIO13), U2.3 (A2)
DA6: J1.31 (GCLK2/GPIO6), U2.4 (A3)
DA7: J1.29 (GCLK1/GPIO5), U2.5 (A4)
DB0: J2.8, J4.8, U1.13 (B1)
DB1: J2.21, J4.20, U1.12 (B2)
DB2: J2.7, J4.7, U1.11 (B3)
DB3: J2.20, J4.19, U1.10 (B4)
DB4: J2.6, J4.6, U2.13 (B1)
DB5: J2.19, J4.18, U2.12 (B2)
DB6: J2.5, J4.5, U2.11 (B3)
DB7: J2.18, J4.17, U2.10 (B4)
GND: C1.2, C2.2, C3.2, C4.2, C5.2, C6.2, C7.1, C8.2, C9.1, C10.1, D2.1 (K), D3.2 (A), D4.1 (K), D5.1 (K), J1.6 (GND), J1.9 (GND), J1.14 (GND), J1.20 (GND), J1.25 (GND), J1.30 (GND), J1.34 (GND), J1.39 (GND), J2.3, J2.4, J2.13, J2.17, J2.23, J2.26, J3.8, J3.9, J3.12, J4.3, J4.4, J4.13, J4.16, J4.22, J4.25, J5.5, J7.2, J8.2, J9.2, J10.2, R1.1, SW1.2, TP1.1, U1.7 (GND), U2.7 (GND), U3.7 (GND), U4.2 (GND), U4.3 (GND), U5.1 (GND), U5.4 (+Vo), U6.3 (GND), U7.3 (GND)
GPIO0_A: J1.27 (ID_SD/GPIO0), J3.5, U3.4 (A3)
GPIO0_B: J3.13, U3.11 (B3)
GPIO1_A: J1.28 (ID_SC/GPIO1), J3.6, U3.5 (A4)
GPIO1_B: J3.14, U3.10 (B4)
GPIO3_A: J1.5 (SCL/GPIO3), J9.1, R14.1, SW1.1
MISO_A: J1.21 (MISO0/GPIO9), J3.4
MOSI_A: J1.19 (MOSI0/GPIO10), J3.3
unnamed: D1.2 (A), J7.1, J8.1
unnamed: D2.2 (A), R10.2
unnamed: D3.1 (K), R11.2
unnamed: D4.2 (A), R12.2
unnamed: D5.2 (A), R13.2
unnamed: J6.2, J6.4, U4.4 (Vout)
unnamed: J6.6, JP4.1, U4.1 (Vin)
unnamed: C8.1, J6.7, U5.3 (0V)
unnamed: C7.2, JP3.1, U5.2 (Vin)
OE: J1.18 (GPIO24), JP1.1, R1.2, U1.8 (OE), U2.8 (OE), U3.8 (OE)
PWRFAIL_A: J1.22 (GPIO25), U3.2 (A1)
PWRFAIL_B: J2.11, J4.11, U3.13 (B1)
RX_A: J1.10 (GPIO15/RXD), J3.11
SPICS_A: J1.15 (GPIO22), J3.2
SPISCK_A: J1.23 (SCLK0/GPIO11), J3.1
TX_A: J1.8 (GPIO14/TXD), J3.10
~MAINSTAT_A: J1.32 (PWM0/GPIO12), Q1.2 (S), R2.1
~MAINSTAT_B: J2.12, J4.12, Q1.3 (D), R4.1
~PODSTAT_A: J1.26 (~CE1/GPIO7), U6.4 (Y)
~PODSTAT_B: J2.25, J4.24, U6.2 (A)
~PODprsnt_A: J1.16 (GPIO23), U3.3 (A2)
~PODprsnt_B: J2.9, J4.9, U3.12 (B2)
~RESET_A: J1.24 (~CE0/GPIO8), Q2.2 (S), R3.1
~RESET_B: J2.24, J4.23, Q2.3 (D), R5.1
~SYNC_A: J1.13 (GPIO27), J3.7, U7.4 (Y)
~SYNC_B: J2.10, J4.10, U7.2 (A)

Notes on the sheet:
SYNC
~{PODSTAT}
~{RESET}
~{MAINSTAT}
Notes: C10 can be omitted
Not used yet (GPIO 3, 5, 7, 11, 12)

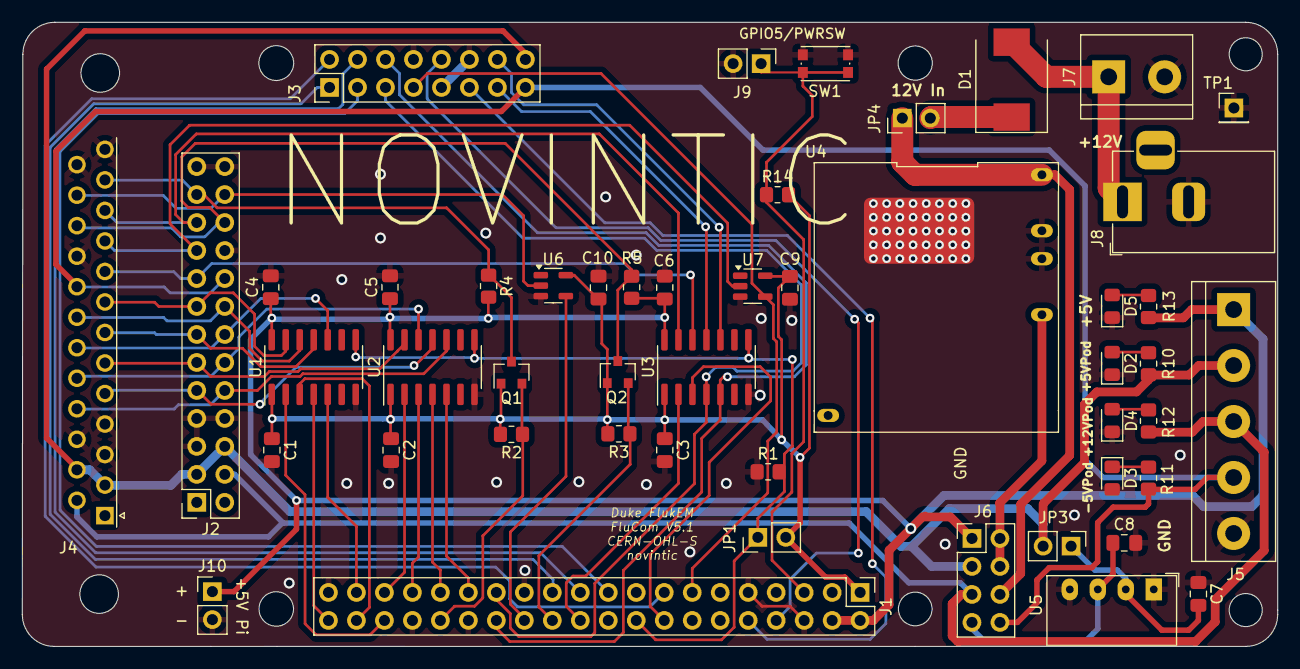
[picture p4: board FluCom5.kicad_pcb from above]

Board: 2 copper layers, 114.0 x 56.7 mm, 49 parts (0 on the bottom side), 56 nets.

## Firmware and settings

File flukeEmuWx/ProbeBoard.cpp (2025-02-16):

/***************************************************************************
This work is free software; you can redistribute it and/or modify it under
the terms of the GNU General Public License Version 2 as published by the
Free Software Foundation. This work is distributed in the hope that it will
be useful, but without any warranty; without even the implied warranty of
merchantability or fitness for a particular purpose.
See the GNU General Public License for more details. You should have
received a copy of the GNU General Public License along with this program;
if not, write to:
Free Software Foundation,
Inc., 59 Temple Place, Suite 330,
Boston, MA 02111-1307 USA
****************************************************************************/
// By Clemens (novintic), 2022

// FluCom3 Probe board communication
// Runs an extra thread to communicate with the probe board
// over SPI.

#include "ProbeBoard.h"
#include "wx/wx.h"

#ifdef LINUX_SPI
#include <sys/ioctl.h>
#include <linux/spi/spidev.h>
#endif // LINUX_SPI
#ifdef WIRINGPI
#include "wiringPi.h"
#endif // WIRINGPI

ProbeBoard::ProbeBoard() : wxThread(wxTHREAD_JOINABLE)
{
    m_reset = true;
    m_run   = true;
    m_exit  = false;
    m_execIntUs = 1000; // run once per ms
    hSPIDev = 0;
    m_commCnt = 0;
    m_commErrors = 0;
    m_probeBoardUp = true;  // Assume board is there
    // init SPI messages
    memset(&m_outMsg, 0, sizeof(PROBE_SPIOUT_REGS_t));
    m_outMsg.header  = 0x5A;   // #define SPI_INMSG_HEAD      0xA5
    m_outMsg.trailer = 0xA5;   // #define SPI_INMSG_TAIL      0x5A

    memset(&m_inMsg, 0, sizeof(PROBE_SPIIN_REGS_t));
    m_inMsg.header   = 0xA5;   // #define SPI_INMSG_HEAD     0xA5
//    m_inMsg.pulseCfg = 0;
//    m_inMsg.rstCmd   = 0;
    m_inMsg.res[0]   = 0x11;
    m_inMsg.res[1]   = 0x22;
    m_inMsg.res[2]   = 0x33;
    m_inMsg.trailer  = 0x5A;   // #define SPI_INMSG_TAIL     0x5A

    m_pPodProbe      = NULL;
    m_pEvSigGen      = NULL;
}

ProbeBoard::~ProbeBoard()
{
}

// The thread execution function
wxThread::ExitCode ProbeBoard::Entry()
{
    int64_t lastT = 0;
    wxLogDebug("PBOARD: COMM started");
    // loop
    while(!m_exit)
    {
        //wxLongLong wxStT = wxGetLocalTimeMillis();
        wxLongLong wxStT = wxGetUTCTimeUSec();
        int64_t stT = wxStT.GetValue();

        if(m_reset)
        {
            reset();
            m_reset = false;
        }
        if(m_run)
        {
            probeBoardComm();
        }
        //wxLongLong wxEnT = wxGetLocalTimeMillis();
        wxLongLong wxEnT = wxGetUTCTimeUSec();
        int64_t enT = wxEnT.GetValue();
        int64_t tdiff = enT - stT;
        // update stats if emu has run
        if(m_run)
        {
            m_totEmuTime += tdiff;
            m_cntEmuRuns++;
            m_avgEmuTime = m_totEmuTime / m_cntEmuRuns;
            m_maxEmuTime = tdiff > m_maxEmuTime ? tdiff : m_maxEmuTime;
        }

        if((enT - lastT) >= 1000000)
        {
            lastT = enT;
            //dispStats();

            // board detection
            bool lastState = m_probeBoardUp;
            if (m_commErrors < 10)
                m_probeBoardUp = true; // assume board ok
            else
                m_probeBoardUp = false;
            if(lastState != m_probeBoardUp)
                wxLogDebug("Probeboard %s\n", m_probeBoardUp ? "up":"down");
            m_commErrors = 0;
        }

        int slt = (m_execIntUs - tdiff) >= 0 ? m_execIntUs - tdiff : 0;

        // Sleep
        //wxMicroSleep(slt);
        wxMilliSleep(10);
    }

    return 0;
}

// Start, pause, reset, end emulation thread
void ProbeBoard::execCtrl(int cmd)
{
    if(cmd == ECMD_RESET)
        m_reset = true;
    else if(cmd == ECMD_RUN)
        m_run = true;
    else if(cmd == ECMD_PAUSE)
        m_run = false;
    else if(cmd == ECMD_EXIT)
        m_exit = true;
}


void ProbeBoard::reset(void)
{
    init();

}

void ProbeBoard::init(void)
{
    // open SPI
	hSPIDev = openSPI("/dev/spidev0.0", 1000000);
#ifdef WIRINGPI
    pinMode (GPIO_SPI_CS, OUTPUT);
    digitalWrite(GPIO_SPI_CS, HIGH);
#endif // WIRINGPI

    // Test comm with board
    m_commErrors = 0;
    probeBoardComm();
    if (m_commErrors > 0)
        m_probeBoardUp = false;
    else
        m_probeBoardUp = true;
    wxLogDebug("Probeboard detected: %s\n", m_probeBoardUp ? "YES":"NO");
}

bool ProbeBoard::probeBoardDetected(void)
{
    return m_probeBoardUp;
}

void ProbeBoard::regPodProbe(emuPodProbe *pPodProbe)
{
    m_pPodProbe = pPodProbe;
}

void ProbeBoard::regEvSigGen(emuEvCntSigGen *pEvSigGen)
{
    m_pEvSigGen = pEvSigGen;
}

uint32_t ProbeBoard::getProbeStatus(void)
{
    return m_outMsg.levStat;
}

void ProbeBoard::setPulseMode(uint32_t pulseCfg)
{
    m_inMsg.pulseCfg = pulseCfg;
}

uint32_t ProbeBoard::getCount(void)
{
    return m_outMsg.evCount;
}
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

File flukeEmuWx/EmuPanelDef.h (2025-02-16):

/***************************************************************************
This work is free software; you can redistribute it and/or modify it under
the terms of the GNU General Public License Version 2 as published by the
Free Software Foundation. This work is distributed in the hope that it will
be useful, but without any warranty; without even the implied warranty of
merchantability or fitness for a particular purpose.
See the GNU General Public License for more details. You should have
received a copy of the GNU General Public License along with this program;
if not, write to:
Free Software Foundation,
Inc., 59 Temple Place, Suite 330,
Boston, MA 02111-1307 USA
****************************************************************************/
// By Clemens (novintic), 2022

#ifndef EMUPANELDEF_H_INCLUDED
#define EMUPANELDEF_H_INCLUDED


// Key definitions (Source FlukeEm by AAdam Courchesne (@onecircuit))
#define KEY_0              0
#define KEY_1              1
#define KEY_2              2
#define KEY_3              3
#define KEY_4              4
#define KEY_5              5
#define KEY_6              6
#define KEY_7              7
#define KEY_8              8
#define KEY_9              9
#define KEY_A             10
#define KEY_B             11
#define KEY_C             12
#define KEY_D             13
#define KEY_E             14
#define KEY_F             15
#define KEY_LEARN         16    // (
#define KEY_IO_VIEW       18    // %
#define KEY_RAM_VIEW      17    // *
#define KEY_ROM_VIEW      19    // #
#define KEY_AUTO          20    // backslash
#define KEY_BUS_TEST      21    // "
#define KEY_ROM_TEST      22    // $
#define KEY_RAMLONG_TEST  23    // /
#define KEY_RAMSHORT_TEST 24
#define KEY_IO_TEST       25
#define KEY_PRIOR         26
#define KEY_MORE          27
#define KEY_ENTER_YES     28
#define KEY_CLEAR_NO      29
#define KEY_STS_CTL       30    //' '
#define KEY_READ_TS       31    // G
#define KEY_WRITE_TS      32    // H
#define KEY_RAMP          33    // L
#define KEY_WALK          34    // M
#define KEY_TOGGL_ADDR    35    // Q
#define KEY_TOGGL_DATA    36    // R
#define KEY_CONT          37    // V
#define KEY_REPEAT        38    // ;
#define KEY_LOOP          39    // ,
#define KEY_STOP          40    // W
#define KEY_RUN_UUT       41    // @
#define KEY_PROGRAM       42    // I
#define KEY_LABEL         43    // T
#define KEY_GOTO          44    // U
#define KEY_IF            45    // N
#define KEY_GR_THAN       46    // O
#define KEY_EQUALS        47    // P
#define KEY_AND           48    // X
#define KEY_OR            49    // =
#define KEY_SHIFT_LEFT    50    // Y
#define KEY_SHIFT_RIGHT   51    // <
#define KEY_INCR          52    // Z
#define KEY_DECR          53    // >
#define KEY_COMPL         54    // -
#define KEY_EXEC          55    // J
#define KEY_REG           56    // +
#define KEY_READ_PROBE    57    // ?
#define KEY_READ_TAPE     58
#define KEY_WRITE_TAPE    59
#define KEY_SYNC          60
#define KEY_SETUP         61    // .
#define KEY_DISPL         62    // S
#define KEY_AUX_IF        63    // K

#define KEY_HIGH_DOWN     64
#define KEY_HIGH_UP       65

#define KEY_LOW_DOWN      66
#define KEY_LOW_UP        67

#define KEY_EMU_BASE      128
#define KEY_EMU_ALPHAKEYS 128
#define KEY_EMU_SETTINGS  129

#define KEY_NOKEY         255

#define ROW00KEYS   {KEY_LEARN,    KEY_RAM_VIEW,   KEY_EMU_ALPHAKEYS,KEY_AUTO,         KEY_BUS_TEST,      KEY_ROM_TEST}
#define ROW01KEYS   {KEY_IO_VIEW,  KEY_ROM_VIEW,   KEY_EMU_SETTINGS,     KEY_RAMLONG_TEST, KEY_RAMSHORT_TEST, KEY_IO_TEST}
#define ROW02KEYS   {KEY_NOKEY,    KEY_C,          KEY_8,          KEY_4,            KEY_0,             KEY_ENTER_YES}
#define ROW03KEYS   {KEY_NOKEY,    KEY_D,          KEY_9,          KEY_5,            KEY_1,             KEY_CLEAR_NO}
#define ROW04KEYS   {KEY_NOKEY,    KEY_E,          KEY_A,          KEY_6,            KEY_2,             KEY_PRIOR}
#define ROW05KEYS   {KEY_STS_CTL,  KEY_F,          KEY_B,          KEY_7,            KEY_3,             KEY_MORE}
#define ROW06KEYS   {KEY_READ_TS,  KEY_RAMP,       KEY_TOGGL_ADDR, KEY_CONT,         KEY_REPEAT,        KEY_LOOP}
#define ROW07KEYS   {KEY_WRITE_TS, KEY_WALK,       KEY_TOGGL_DATA, KEY_STOP,         KEY_RUN_UUT,       KEY_SETUP}
#define ROW08KEYS   {KEY_PROGRAM,  KEY_IF,         KEY_DISPL,      KEY_AND,          KEY_OR,            KEY_READ_PROBE}
#define ROW09KEYS   {KEY_EXEC,     KEY_GR_THAN,    KEY_LABEL,      KEY_SHIFT_LEFT,   KEY_SHIFT_RIGHT,   KEY_REG}
#define ROW10KEYS   {KEY_AUX_IF,   KEY_EQUALS,     KEY_GOTO,       KEY_INCR,         KEY_DECR,          KEY_COMPL}
#define ROW11KEYS   {KEY_READ_TAPE,KEY_WRITE_TAPE, KEY_SYNC,       KEY_HIGH_DOWN,    KEY_LOW_DOWN,      KEY_NOKEY}

#define KEYMAP  {ROW00KEYS,ROW01KEYS,ROW02KEYS,ROW03KEYS,ROW04KEYS,ROW05KEYS,ROW06KEYS,ROW07KEYS,ROW08KEYS,ROW09KEYS,ROW10KEYS,ROW11KEYS}

#define KEYCOLNUM   12
#define KEYROWNUM   6
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

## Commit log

2022-04-09 Do not track
2022-04-09 Initial upload
    [FluCom2-B_Cu.gbr, FluCom2-B_Mask.gbr, FluCom2-B_Paste.gbr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]
2022-06-17 FlukeEmuWx.cbp: switch to files in new Z80 emulator
2022-08-19 Master (#8)
    * new probeboard class
    * Update readme.md
    Added run instructions
    * Update readme.md
    typo
    * Create manual.md
    A first attempt a sort of manual
    * Update manual.md
    typos!!!
    * Update manual.md
    update
    * Parse command line to allow starting fullscreen
    * Update EmuPanel.cpp
    * Added free Z80 emulator source
    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
    [FluCom2.kicad_pcb, FluCom2.kicad_sch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]
2022-11-25 Delete Build Manual and BOM.pdf
    Replaced file with new version and new name
2022-11-25 Add files via upload
    New version of manual (includes changes necessary for using the probe add-on board) and new filename.
2022-11-25 First public release of probe board.
    [ProbeBoardPublic-B_Cu.gbr, ProbeBoardPublic-B_Mask.gbr, ProbeBoardPublic-B_Paste.gbr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]
2023-01-01 Changed J3 in schematic to alternate numbering
    Changed J3 in schematic to alternate numbering to make it consistent with the physical footprint used on the board
2023-01-01 Changed numbering of J3 in build manual schematic
    Changed J3 in build manual's schematic to alternate numbering to make it consistent with the physical footprint used on the board
2023-04-16 Add files via upload
    Increased track with of +5V POD rail (should be able to provide up to 2A for larger pods like 68K)
    [FluCom3 - SOIC.kicad_pcb]
2023-04-16 Add files via upload
    Increased track width of +5V POD rail (should be able to provide up to 2A for larger pods like 68K)
    [FluCom3-B_Cu.gbr, FluCom3-B_Mask.gbr, FluCom3-B_Paste.gbr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]
2024-05-09 Add files via upload
    Uploaded ProbeBoard Public V5
    [ProbeBoardPublicV5-B_Cu.gbr, ProbeBoardPublicV5-B_Mask.gbr, ProbeBoardPublicV5-B_Paste.gbr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]
2024-05-09 Add files via upload
    Uploaded FluCom V5
    [FluCom.xlsx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]
2024-05-19 Update readme.txt
    About the fuse F1
2024-10-06 Add files via upload
    Removed 40 Pin connector vom Gerbers and production files to avoid confusion
    [ProbeBoardPublicV5-B_Cu.gbr, ProbeBoardPublicV5-B_Mask.gbr, ProbeBoardPublicV5-B_Paste.gbr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]
2024-12-05 Add files via upload
    Added notes about 'larger' PODs and power supply
2025-01-12 fixed mode set output
    [EmuPodProbe.cpp]
2025-01-12 fixed probe com
2025-01-12 hi-low keys fixed, added numlock enter, key display on alt, probe LEDS
    [EmuPanelDef.h, EmuPodProbe.cpp, ProbeBoard.cpp]
2025-01-12 Probe sounds using wxsound and SDL, alpha keys, emu settings menu key
2025-01-12 probe sound off by default
2025-01-12 Revert "Pull main changes to devmain (#9)"
    This reverts commit b06e7216cb19aedc7d3f1abd690329d858e026d4.
    [FluCom.xlsx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]
2025-02-16 User emu speed cli switch, probeboard detetcion, probe LED upgrade, memory leak fix
    [EmuPanelDef.h]
2025-02-16 fixed samplerate

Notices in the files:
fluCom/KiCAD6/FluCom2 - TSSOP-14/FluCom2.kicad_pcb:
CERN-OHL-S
